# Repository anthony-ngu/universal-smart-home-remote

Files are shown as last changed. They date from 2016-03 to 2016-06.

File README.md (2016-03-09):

# Universal Smart Home Remote
The universal remote for smart home devices in the form of a button!

Features:
* LED Screen to provide visual input (battery life, device selected, value selected, etc.)
* Neopixel Ring (because who doesn't love feedback through colors?)
* Wireless Charging
* Battery Powered
* Push Button + Rotational Input
* Microcontroller with WiFi (bluetooth is a plus) - Particle Photon

Connected Devices: (Right now, a rudimentary static pairing)
* Yamaha Receiver
* Wemo Switch

[Check out more info on the project here!](https://www.hackster.io/anthony-ngu/universal-home-button-wirelessly-powered-896f3c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)

This is still a work in progress (Looking to perfect the enclosure and to get it working with a home automation hub)

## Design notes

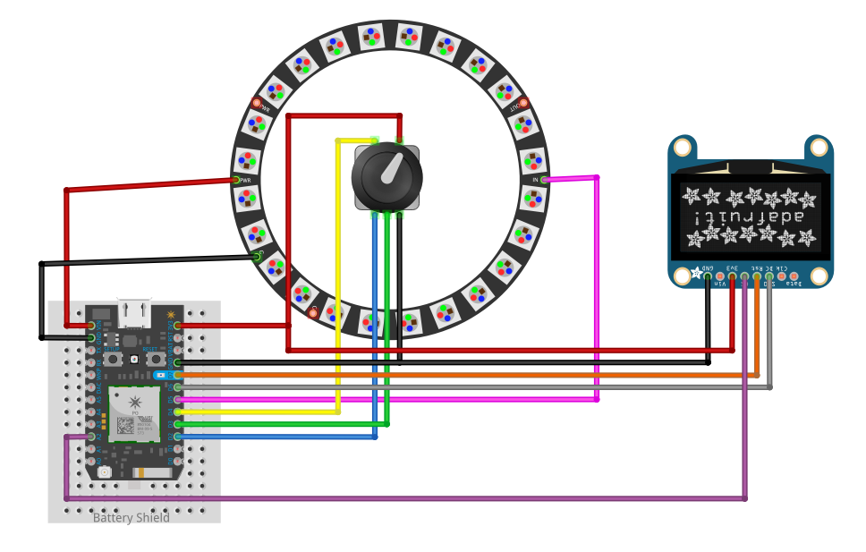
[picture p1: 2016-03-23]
Fritzing-diagram.png

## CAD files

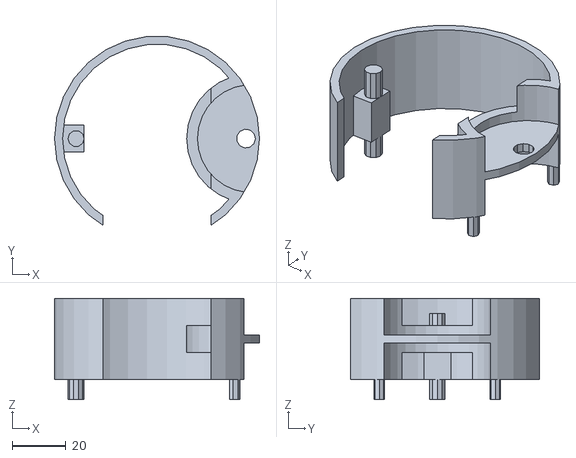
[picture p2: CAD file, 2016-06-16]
3d-prints/inner-barrier.stl
76.0 x 70.0 x 37.5

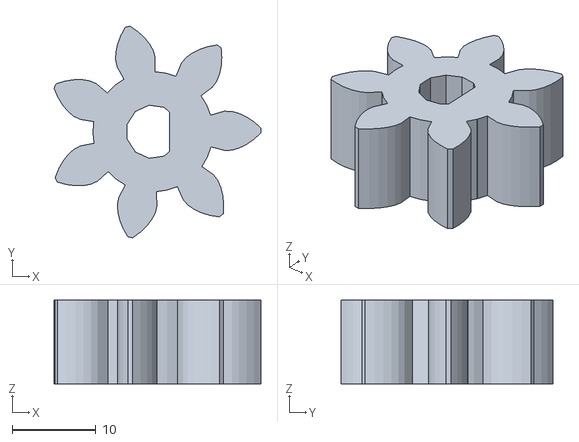
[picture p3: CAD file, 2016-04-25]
3d-prints/inner-gear.stl
24.7 x 25.3 x 10.0

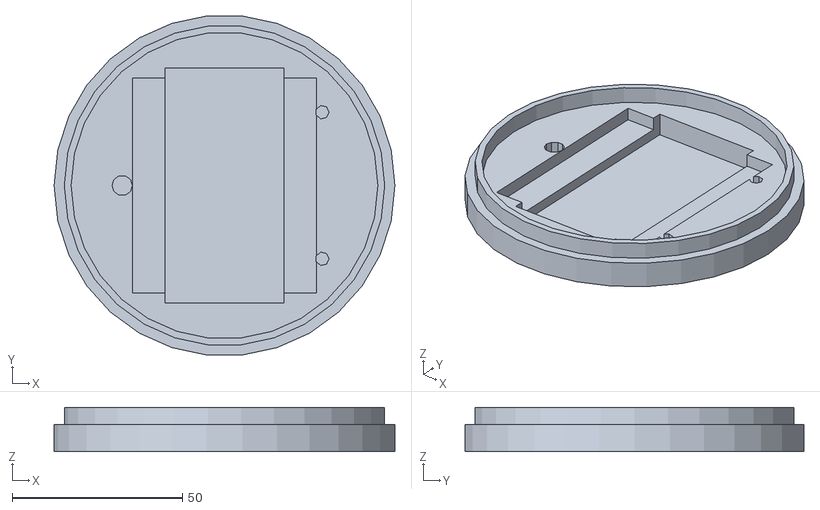
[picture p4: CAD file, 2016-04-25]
3d-prints/bottom-layer.stl
100.0 x 99.5 x 13.0

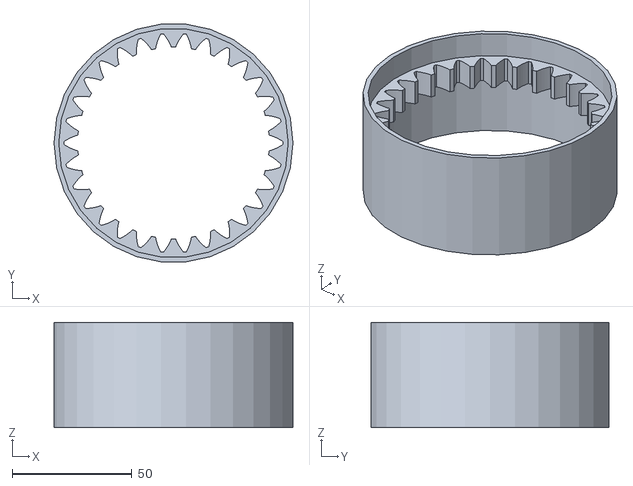
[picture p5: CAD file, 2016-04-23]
3d-prints/outer-gear.stl
100.0 x 99.5 x 44.0

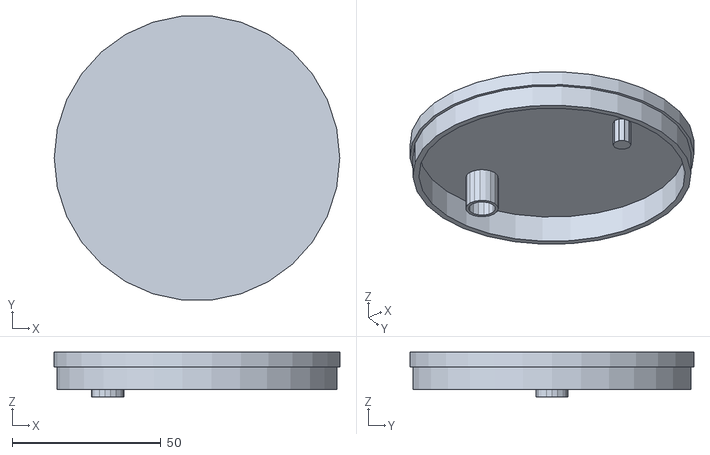
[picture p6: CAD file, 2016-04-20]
3d-prints/top-layer.stl
96.0 x 95.5 x 15.0

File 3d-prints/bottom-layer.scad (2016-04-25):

include <inner-barrier.scad>

// lower lid
union()
{
    // The Base
    translate([0,0,-21])
    difference()
    {
        cylinder(h = 8, r = 50, center = true);
        translate([0,0,2])cube([35,69,10],center=true); //wireless charger
        translate([0,0,3])cube([54,63,5.8],center=true);// li-ion battery 2000mah
        
        // The connector rods
        translate([-30,0,2])cylinder(h=10,r=3,center=true);
        translate([28.7,21.5,2])cylinder(h=10,r=2,center=true);
        translate([28.7,-21.5,2])cylinder(h=10,r=2,center=true);
    }
    
    // Inner Rim for combining pieces
    difference()
    {
        translate([0,0,-16])cylinder(h = 8, r = 47, center = true);
        translate([0,0,-16])cylinder(h = 8, r = 45, center = true);
    }
    
    //inner_barrier();
    
}

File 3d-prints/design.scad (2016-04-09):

include <gear.scad>
include <outer-gear.scad>
include <inner-gear.scad>
include <bottom-layer.scad>
include <top-layer.scad>

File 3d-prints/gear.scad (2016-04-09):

//////////////////////////////////////////////////////////////////////////////////////////////
// Public Domain Parametric Involute Spur Gear (and involute helical gear and involute rack)
// version 1.1
// by Leemon Baird, 2011, Leemon@Leemon.com
//http://www.thingiverse.com/thing:5505
//
// This file is public domain.  Use it for any purpose, including commercial
// applications.  Attribution would be nice, but is not required.  There is
// no warranty of any kind, including its correctness, usefulness, or safety.
// 
// This is parameterized involute spur (or helical) gear.  It is much simpler and less powerful than
// others on Thingiverse.  But it is public domain.  I implemented it from scratch from the 
// descriptions and equations on Wikipedia and the web, using Mathematica for calculations and testing,
// and I now release it into the public domain.
//
//		http://en.wikipedia.org/wiki/Involute_gear
//		http://en.wikipedia.org/wiki/Gear
//		http://en.wikipedia.org/wiki/List_of_gear_nomenclature
//		http://gtrebaol.free.fr/doc/catia/spur_gear.html
//		http://www.cs.cmu.edu/~rapidproto/mechanisms/chpt7.html
//
// The module gear() gives an involute spur gear, with reasonable defaults for all the parameters.
// Normally, you should just choose the first 4 parameters, and let the rest be default values.
// The module gear() gives a gear in the XY plane, centered on the origin, with one tooth centered on
// the positive Y axis.  The various functions below it take the same parameters, and return various
// measurements for the gear.  The most important is pitch_radius, which tells how far apart to space
// gears that are meshing, and adendum_radius, which gives the size of the region filled by the gear.
// A gear has a "pitch circle", which is an invisible circle that cuts through the middle of each
// tooth (though not the exact center). In order for two gears to mesh, their pitch circles should 
// just touch.  So the distance between their centers should be pitch_radius() for one, plus pitch_radius() 
// for the other, which gives the radii of their pitch circles.
//
// In order for two gears to mesh, they must have the same mm_per_tooth and pressure_angle parameters.  
// mm_per_tooth gives the number of millimeters of arc around the pitch circle covered by one tooth and one
// space between teeth.  The pitch angle controls how flat or bulged the sides of the teeth are.  Common
// values include 14.5 degrees and 20 degrees, and occasionally 25.  Though I've seen 28 recommended for
// plastic gears. Larger numbers bulge out more, giving stronger teeth, so 28 degrees is the default here.
//
// The ratio of number_of_teeth for two meshing gears gives how many times one will make a full 
// revolution when the the other makes one full revolution.  If the two numbers are coprime (i.e. 
// are not both divisible by the same number greater than 1), then every tooth on one gear
// will meet every tooth on the other, for more even wear.  So coprime numbers of teeth are good.
//
// The module rack() gives a rack, which is a bar with teeth.  A rack can mesh with any
// gear that has the same mm_per_tooth and pressure_angle.
//
// Some terminology: 
// The outline of a gear is a smooth circle (the "pitch circle") which has mountains and valleys
// added so it is toothed.  So there is an inner circle (the "root circle") that touches the 
// base of all the teeth, an outer circle that touches the tips of all the teeth,
// and the invisible pitch circle in between them.  There is also a "base circle", which can be smaller than
// all three of the others, which controls the shape of the teeth.  The side of each tooth lies on the path 
// that the end of a string would follow if it were wrapped tightly around the base circle, then slowly unwound.  
// That shape is an "involute", which gives this type of gear its name.
//
//////////////////////////////////////////////////////////////////////////////////////////////

//An involute spur gear, with reasonable defaults for all the parameters.
//Normally, you should just choose the first 4 parameters, and let the rest be default values.
//Meshing gears must match in mm_per_tooth, pressure_angle, and twist,
//and be separated by the sum of their pitch radii, which can be found with pitch_radius().
module gear (
	mm_per_tooth    = 3,    //this is the "circular pitch", the circumference of the pitch circle divided by the number of teeth
	number_of_teeth = 11,   //total number of teeth around the entire perimeter
	thickness       = 6,    //thickness of gear in mm
	hole_diameter   = 3,    //diameter of the hole in the center, in mm
	twist           = 0,    //teeth rotate this many degrees from bottom of gear to top.  360 makes the gear a screw with each thread going around once
	teeth_to_hide   = 0,    //number of teeth to delete to make this only a fraction of a circle
	pressure_angle  = 28,   //Controls how straight or bulged the tooth sides are. In degrees.
	clearance       = 0.0,  //gap between top of a tooth on one gear and bottom of valley on a meshing gear (in millimeters)
	backlash        = 0.0   //gap between two meshing teeth, in the direction along the circumference of the pitch circle
) {
	assign(pi = 3.1415926)
	assign(p  = mm_per_tooth * number_of_teeth / pi / 2)  //radius of pitch circle
	assign(c  = p + mm_per_tooth / pi - clearance)        //radius of outer circle
	assign(b  = p*cos(pressure_angle))                    //radius of base circle
	assign(r  = p-(c-p)-clearance)                        //radius of root circle
	assign(t  = mm_per_tooth/2-backlash/2)                //tooth thickness at pitch circle
	assign(k  = -iang(b, p) - t/2/p/pi*180) {             //angle to where involute meets base circle on each side of tooth
		difference() {
			for (i = [0:number_of_teeth-teeth_to_hide-1] )
				rotate([0,0,i*360/number_of_teeth])
					linear_extrude(height = thickness, center = true, convexity = 10, twist = twist)
						polygon(
							points=[
								[0, -hole_diameter/10],
								polar(r, -181/number_of_teeth),
								polar(r, r<b ? k : -180/number_of_teeth),
								q7(0/5,r,b,c,k, 1),q7(1/5,r,b,c,k, 1),q7(2/5,r,b,c,k, 1),q7(3/5,r,b,c,k, 1),q7(4/5,r,b,c,k, 1),q7(5/5,r,b,c,k, 1),
								q7(5/5,r,b,c,k,-1),q7(4/5,r,b,c,k,-1),q7(3/5,r,b,c,k,-1),q7(2/5,r,b,c,k,-1),q7(1/5,r,b,c,k,-1),q7(0/5,r,b,c,k,-1),
								polar(r, r<b ? -k : 180/number_of_teeth),
								polar(r, 181/number_of_teeth)
							],
 							paths=[[0,1,2,3,4,5,6,7,8,9,10,11,12,13,14,15,16]]
						);
			cylinder(h=2*thickness+1, r=hole_diameter/2, center=true, $fn=20);
		}
	}
};	
//these 4 functions are used by gear
function polar(r,theta)   = r*[sin(theta), cos(theta)];                            //convert polar to cartesian coordinates
function iang(r1,r2)      = sqrt((r2/r1)*(r2/r1) - 1)/3.1415926*180 - acos(r1/r2); //unwind a string this many degrees to go from radius r1 to radius r2
function q7(f,r,b,r2,t,s) = q6(b,s,t,(1-f)*max(b,r)+f*r2);                         //radius a fraction f up the curved side of the tooth 
function q6(b,s,t,d)      = polar(d,s*(iang(b,d)+t));                              //point at radius d on the involute curve

//a rack, which is a straight line with teeth (the same as a segment from a giant gear with a huge number of teeth).
//The "pitch circle" is a line along the X axis.
module rack (
	mm_per_tooth    = 3,    //this is the "circular pitch", the circumference of the pitch circle divided by the number of teeth
	number_of_teeth = 11,   //total number of teeth along the rack
	thickness       = 6,    //thickness of rack in mm (affects each tooth)
	height          = 120,   //height of rack in mm, from tooth top to far side of rack.
	pressure_angle  = 28,   //Controls how straight or bulged the tooth sides are. In degrees.
	backlash        = 0.0   //gap between two meshing teeth, in the direction along the circumference of the pitch circle
) {
	assign(pi = 3.1415926)
	assign(a = mm_per_tooth / pi) //addendum
	assign(t = a*cos(pressure_angle)-1)         //tooth side is tilted so top/bottom corners move this amount
		for (i = [0:number_of_teeth-1] )
			translate([i*mm_per_tooth,0,0])
				linear_extrude(height = thickness, center = true, convexity = 10)
					polygon(
						points=[
							[-mm_per_tooth * 3/4,                 a-height],
							[-mm_per_tooth * 3/4 - backlash,     -a],
							[-mm_per_tooth * 1/4 + backlash - t, -a],
							[-mm_per_tooth * 1/4 + backlash + t,  a],
							[ mm_per_tooth * 1/4 - backlash - t,  a],
							[ mm_per_tooth * 1/4 - backlash + t, -a],
							[ mm_per_tooth * 3/4 + backlash,     -a],
							[ mm_per_tooth * 3/4,                 a-height],
						],
						paths=[[0,1,2,3,4,5,6,7]]
					);
};
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

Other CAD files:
3d-prints/inner-barrier.scad
3d-prints/inner-gear.scad
3d-prints/outer-gear.scad
3d-prints/top-layer.scad

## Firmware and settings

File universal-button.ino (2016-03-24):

// #define JSMN_PARENT_LINKS 1 // by defining it JSMN will include links to the parents - does not work right now..

#include "application.h"
#include "SparkFunMAX17043/SparkFunMAX17043.h"
#include "SparkFunMicroOLED/SparkFunMicroOLED.h"
#include "math.h"
#include "neopixel/neopixel.h"
// #include "JSMNSpark/JSMNSpark.h" // for more info on JSMN check out @ https://github.com/zserge/jsmn
#include "clickButton/clickButton.h"
#include "menuItem.h"

SYSTEM_MODE(AUTOMATIC);

// IMPORTANT: Set pixel COUNT, PIN and TYPE
#define PIXEL_PIN D5
#define PIXEL_COUNT 24
#define PIXEL_TYPE WS2812B

// Timer Globals
long lastActionTime;
bool standbyMode = false;

// Button Globals
#define BUTTON_PIN D4
ClickButton button1(BUTTON_PIN, HIGH);
int function = 0;

// Neopixel Globals
Adafruit_NeoPixel strip = Adafruit_NeoPixel(PIXEL_COUNT, PIXEL_PIN, PIXEL_TYPE);
#define BRIGHTNESS 10
int fadeValue = 0;
int fadeAdder = 1;
int MAX_FADE_VALUE = 500;

// Rotary Encoder Globals
#define ENC_A_PIN D2
#define ENC_B_PIN D3
    
volatile int lastEncoded = 0;
volatile long encoderValue = 0;
long lastencoderValue = 0;
int lastMSB = 0;
int lastLSB = 0;

// OLED Globals
MicroOLED oled;
bool screenOn = true;
long screenSaverDelay = 60000; // 60 seconds

// Battery Monitoring Globals
double voltage = 0; // Variable to keep track of LiPo voltage
double soc = 0; // Variable to keep track of LiPo state-of-charge (SOC)
bool alert; // Variable to keep track of whether alert has been triggered
int chargingLedValue = 0;
double MAX_LED_VALUE = 100.0;
bool ledValIncreasing = true;
long lastLedChangeTime = (long)millis(); // get current time
long ledAnimationDelay = 100;
int consistencyCounter = 0;
int consistencyCounterLimit = 3;
char batteryInfo[30];

// Setup Globals
int i = 0;
// String headerText = "Omnii";
// String selectionText = "";

String buttonText = "Not Pressed";
String encoderText = "0";
MenuItem rootMenuItem;
MenuItem currentMenuItem;

// Function Declarations
void encoder_counter();
void goIntoStandby();
void printData(char * str);

void setup()
{
    Particle.publish("starting-setup");
    lastActionTime = (long)millis();
    
    // Initialize Encoder
    pinMode(ENC_A_PIN, INPUT_PULLUP); 
    pinMode(ENC_B_PIN, INPUT_PULLUP);
    
    // attach interrupts
    attachInterrupt(ENC_A_PIN, updateEncoder, CHANGE);
    attachInterrupt(ENC_B_PIN, updateEncoder, CHANGE);

    // Button setup  
    pinMode(BUTTON_PIN, INPUT);
    button1.debounceTime   = 20;   // Debounce timer in ms
    button1.multiclickTime = 250;  // Time limit for multi clicks
    button1.longClickTime  = 1000; // time until "held-down clicks" register
    
    // Neopixel Ring Setup
    strip.begin();
    strip.show(); // Initialize all pixels to 'off'
    strip.setBrightness(BRIGHTNESS); // Stops the LEDs from being blinding
    strip.show();
    
    // Set up the MAX17043 LiPo fuel gauge:
    lipo.begin(); // Initialize the MAX17043 LiPo fuel gauge
    // Quick start restarts the MAX17043 in hopes of getting a more accurate
    // guess for the SOC.
    lipo.quickStart();
    
    // OLED Setup
    oled.begin();    // Initialize the OLED
    oled.clear(ALL); // Clear the display's internal memory
    oled.display();  // Display what's in the buffer (splashscreen)
    delay(1000);     // Delay 1000 ms
    oled.clear(PAGE); // Clear the buffer.
    
    // Info Setup
    char* tempArray[] = {"on", "off"};
    char* tempArray2[] = {"Pandora", "HDMI1", "HDMI2", "HDMI3", "HDMI4"};
    char* tempArray3[] = {"play", "pause", "skip"};
    MenuItem powerItem = MenuItem(String("Power"), tempArray, 2);
    MenuItem volumeItem = MenuItem(String("Volume"), -500, 0, 10);
    MenuItem muteItem = MenuItem(String("Mute"),  tempArray, 2);
    MenuItem inputItem = MenuItem(String("Input"),  tempArray2, 5);
    MenuItem playbackItem = MenuItem(String("Controls"), tempArray3, 3);
    
    MenuItem itemArray[] = {powerItem, volumeItem, muteItem, playbackItem, inputItem};
    MenuItem receiverItem = MenuItem(String("Receiver"), itemArray, 5);
    
    MenuItem wemoItem = MenuItem(String("Wemo"), tempArray, 2);
    
    MenuItem deviceArray[] = {receiverItem, wemoItem};
    
    rootMenuItem = MenuItem(String("Devices"), deviceArray, 2);
    currentMenuItem = rootMenuItem;
}

void loop()
{
    fadingLights();
    if(standbyMode)
    {
        // It just came out of standby
        Particle.publish("waking-up");
        lastActionTime = (long)millis();
        standbyMode = false;
        screenOn = true;
    }
    char str[20];
    sprintf(str, "%d", encoderValue);
    encoderText = str;
    
    button1.Update();
    if (button1.clicks != 0)
    {
        function = button1.clicks;
        if(function == 1)
        {
            // go one level deeper or select
            if(currentMenuItem.optionType == MENU_ARRAY)
            {
                currentMenuItem = currentMenuItem.children[currentMenuItem.selectedIndex];
            }
            else
            {
                currentMenuItem.chooseSelection();   
            }
            buttonText = "SINGLE_CLICK";
            function = 0;
        }else if(function == 2)
        {
            // go one level back
            buttonText = "DOUBLE_CLICK";
            function = 0;
        }
        else if(function == -1) 
        {
            // go back to the home screen
            currentMenuItem = rootMenuItem;
            buttonText = "LONG_CLICK";
            function = 0;
        }else{
            buttonText = "";
        }
        lastActionTime = (long)millis();
        screenOn = true;
    }
    
    // Automatic Standbymode
    if (lastActionTime < (long)millis()-screenSaverDelay)
    {
        screenOn = false;
        oled.clear(PAGE);     // Clear the page
        oled.display();       // Refresh the display
        standbyLights();
        // Put the device into stop mode with wakeup using a change interrupt on one of the encoder pins
        Particle.publish("starting-standby");
        standbyMode = true; // set standbyMode before going into stop mode so that it can recover on restart
        System.sleep(BUTTON_PIN,RISING);
    }
    
    // LiPo and Battery Display
    double pastVoltage = voltage;
    voltage = lipo.getVoltage(); // lipo.getVoltage() returns a voltage value (e.g. 3.93)
    soc = lipo.getSOC(); // lipo.getSOC() returns the estimated state of charge (e.g. 79%)
    sprintf(batteryInfo, "%.1f%%", soc);
    if(pastVoltage<voltage)
    {
        consistencyCounter++;
    }
    else if(pastVoltage>voltage)
    {
        consistencyCounter = 0;
        // standbyLights();
    }

    // if(consistencyCounter > consistencyCounterLimit)
    // {
    //     chargingLights();
    // }

    if(screenOn)
    {
        // LiPo and Battery Display
        oled.setFontType(0);  // Set font to type 0
        oled.clear(PAGE);     // Clear the page
        printBatteryIcon(soc);
        oled.setCursor(15, 0);
        oled.print(batteryInfo);
        int middleX = oled.getLCDWidth() / 2;
        oled.setCursor(middleX - (oled.getFontWidth() * (currentMenuItem.headerText.length()/2)) - 3, 20);
        oled.print(currentMenuItem.headerText);
        // oled.setCursor(0,20);
        // oled.print(buttonText);
        // oled.setCursor(0,30);
        // oled.print(encoderText);
        oled.setCursor(middleX - (oled.getFontWidth() * (currentMenuItem.selectionText.length()/2)) - 3, 40);
        oled.print(currentMenuItem.selectionText);
        oled.display();       // Refresh the display
    }else{
        oled.clear(PAGE);     // Clear the page
        oled.display();       // Refresh the display
    }
}

void printBatteryIcon(double percentage)
{
    for(int i=0;i<10;i++)
    {
        oled.pixel(i,0);
        oled.pixel(i,5);
    }
    for(int i=0;i<5;i++)
    {
        oled.pixel(0,i);
        oled.pixel(10,i);
    }
    for(int i=0;i<4;i++)
    {
        oled.pixel(11,i+1);
    }
    for(int i=0;i<percentage/10;i++)
    {
        for(int j=0;j<5;j++)
        {
            oled.pixel(i,j);
        }
    }
}

void fadingLights()
{
    if(fadeValue == MAX_FADE_VALUE)
    {
        fadeAdder = -1;
    }else if(fadeValue == 0){
        fadeAdder = 1;
    }
    setAllLights(strip.Color(0,0,255*fadeValue/MAX_FADE_VALUE));
    fadeValue += fadeAdder;
}

void setAllLights(uint32_t stripColor)
{
    for (int i = 0; i < 24; i++)
    {
        strip.setPixelColor(i, stripColor);
    }
    strip.show();
}

void standbyLights()
{
    setAllLights(strip.Color(0, 0, 0));
}

void printData(char * str)
{
    oled.clear(PAGE);
    oled.setCursor(0,0);
    oled.print(str);
    oled.display();
    delay(2000);
    oled.clear(PAGE);
}
    
void updateEncoder() {
	int MSB = digitalRead(ENC_A_PIN); //MSB = most significant bit
	int LSB = digitalRead(ENC_B_PIN); //LSB = least significant bit
    	
	int encoded = (MSB << 1) |LSB; //converting the 2 pin value to single number
	int sum  = (lastEncoded << 2) | encoded; //adding it to the previous encoded value
    
	if (sum == 0b1101 || sum == 0b0100 || sum == 0b0010 || sum == 0b1011){
	    encoderValue ++;
	    currentMenuItem.increment();
	}
	if(sum == 0b1110 || sum == 0b0111 || sum == 0b0001 || sum == 0b1000){
	    encoderValue --;
	    currentMenuItem.decrement();
	}
    
	lastEncoded = encoded; //store this value for next time
	lastActionTime = (long)millis();
    screenOn = true;
}

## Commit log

2016-02-03 Added the introduction to the universal button
2016-02-03 Updated app and universal button for communicating (need to send better packet recognition info)
2016-02-03 Made the settings sender recursive to chain the commands properly
2016-02-04 Added preliminary debounce button code + rotary encoder code
2016-02-04 Created a setupInit publish in order to start sending SetupData. Also fixed the jsmn_parse parameters
    [universal-button.ino]
2016-02-04 testing rotary encoder code
2016-02-06 Updated the NeoPixel Pin # and added the OLED and Battery Shield code
2016-02-06 Made the OLED screen show the percentage for battery + a message
2016-02-06 Added printouts to the OLED screen for debugging
2016-02-06 Switched to using ClickButotn library for long click recognition
2016-02-07 Switched rotary encoder code
2016-02-07 Updated the code to print out the data on OLED screen + fixed the Encoder pins
    [universal-button.ino]
2016-02-08 Added MenuItem.h and the code for the Menu (however it's failing on MenuCreation)
    [universal-button.ino]
2016-02-08 Changed the ParseMenuArray function to use the correct size for malloc
    [universal-button.ino]
2016-02-09 attempt to fix hard fault issue
    [universal-button.ino]
2016-02-09 Added back in the correct parsing for INT_RANGE and VALUE_ARRAYS
    [universal-button.ino]
2016-02-09 Issues with rotary encoder, but it sends the basic functions for changing the volume now
    [universal-button.ino]
2016-02-10 Changed the rotary encoder code + menuItem Class to work with Receiver
2016-02-14 Added Wemo Device Code
2016-03-07 Update to have the LEDs change while the battery is charging
2016-03-16 Updated the sleep mode to actually have the particle go into sleep mode and turn off all the leds & lights
2016-03-21 Update the automatic standby mode to break standby on the button press
2016-03-23 Add a fritzing diagram on how to connect components by hand
    [frtizing-diagram.fzz]
2016-03-23 Fix the standby mode and add logging through publish calls
    [universal-button.ino]
2016-04-08 Added openSCAD 3d models and STL files
    [bottom-layer.scad, bottom-layer.stl, design.scad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]
2016-04-09 Updated the scad files to be broken up into components
    [bottom-layer.scad, design.scad, gear.scad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]
2016-04-19 Revision of the base to allow for better placement of components through modular design
    [bottom-layer.scad, bottom-layer.stl, inner-barrier.scad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]
2016-04-20 Added a brace for the rotary encoder in the inner-barrier
    [inner-barrier.scad, inner-barrier.stl]
2016-04-20 Changed the heights on the top layer rods to provide better placement
    [top-layer.scad, top-layer.stl]
2016-04-20 Fixed the brace for the rotary encoder in the inner-barrier
    [inner-barrier.scad, inner-barrier.stl]
2016-04-20 Added a ring around the top layer to provide a better cohesion with the bottom layer when a spring is placed inside
    [top-layer.scad, top-layer.stl]
2016-04-23 Updated the outer gear for the need of an increased height
    [outer-gear.scad, outer-gear.stl]
2016-04-25 Gave more room for the battery in the bottom layer and reduced the inner gear's hole
    [bottom-layer.scad, bottom-layer.stl, inner-gear.stl]
2016-06-16 Updated the inner barrier to place the rotary encoder in the right location for the gear to hit the outside gear
    [inner-barrier.scad, inner-barrier.stl]
